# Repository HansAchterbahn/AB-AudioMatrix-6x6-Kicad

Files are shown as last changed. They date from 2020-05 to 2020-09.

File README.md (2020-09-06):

# AB AudioMatrix 6×6

Active audio matrix (6×6), that can map 6 input channels (1-6) to 6 output channels (A-F). Connection via 3.5 jack cable. Compatible with line signals, aux, headphones and active speakers. Each output channel can map one input channel at a time.

*Fork me and have fun!*

## 1 Content and Structure

| File / Folder | Abbreviation | Description |
| --- | --- | --- |
| /3d/ | 3D models | Files to work with in a 3D CAD program |
| /bom/ | Bill of Material | Files with needed components and corresponding order number from different distributors |
| /case/ | Case for PCB | Files with an example case for the PCBs |
| /doc/ | Documentation | Files needed in README.md to document the repository |
| /gerber/ | Gerber files | Files exported from Board Layout to order the PCBs from a manufacturer |
| /sch/ | Schematic | Additional schematic files |
| /AB-AudioMatrix-6x6.pro | — | Kicad Project File |
| /AB-AudioMatrix-6x6.sch | — | Root schematic files |
| /AB-AudioMatrix-6x6.kicad_pcb | — | PCB / Board Layout File |
| /LICENSE.md | — | File contains project license |
| /README.md | — | Markdown file with the documentation you are reading now |

## 2 Power Supply Modes

| Mode | + | — | ⊥ | Jumper JP1 | U7, R25, R26  | Info |
| --- | --- | --- | --- | --- | --- | --- |
| Symmetric  | +2.5 to +15 V | -2.5 to -15 V | 0V  | Open | not necessary | Highly recommended for good Sound and clearly separated channels  |
| Asymmetric | +5 to +30 V | 0 V | --- | Closed | necessary | Possible, but not recommended; Channels are not clearly separated |

## 3 Pictures

### 3.1 Mounted device

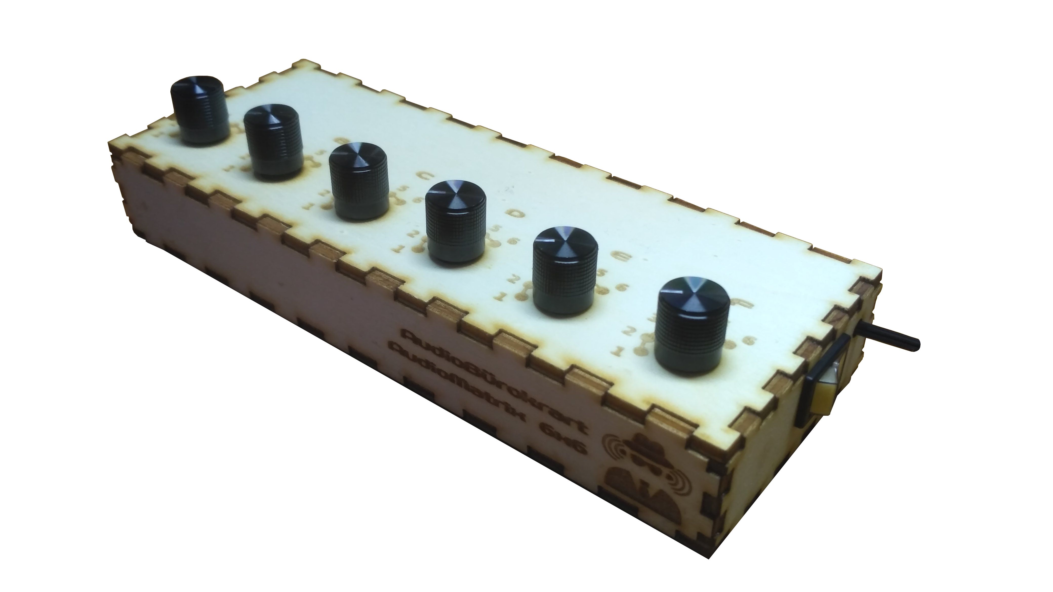
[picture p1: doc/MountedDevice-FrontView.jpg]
Front view

Front view

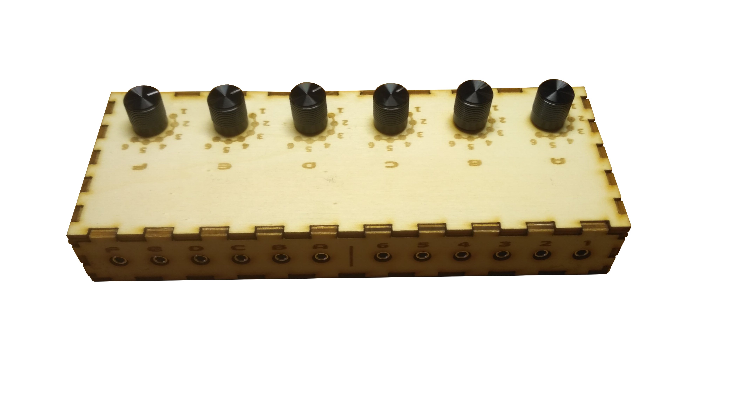
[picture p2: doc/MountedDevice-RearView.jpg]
Rear view

Rear view

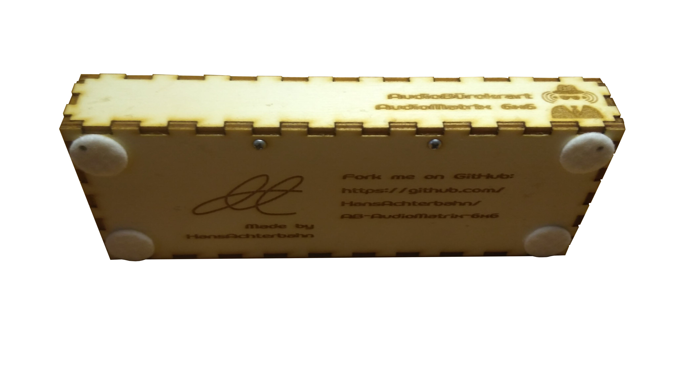
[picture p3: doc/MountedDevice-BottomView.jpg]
Bottom view

Bottom view

### 3.2 Board

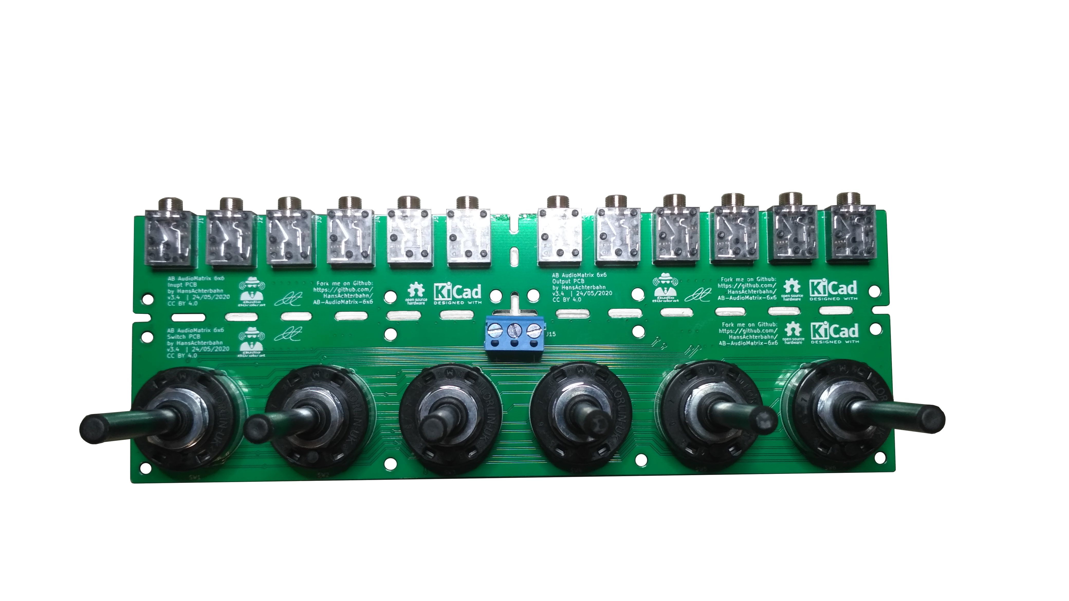
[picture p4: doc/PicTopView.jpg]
Top view

Top view

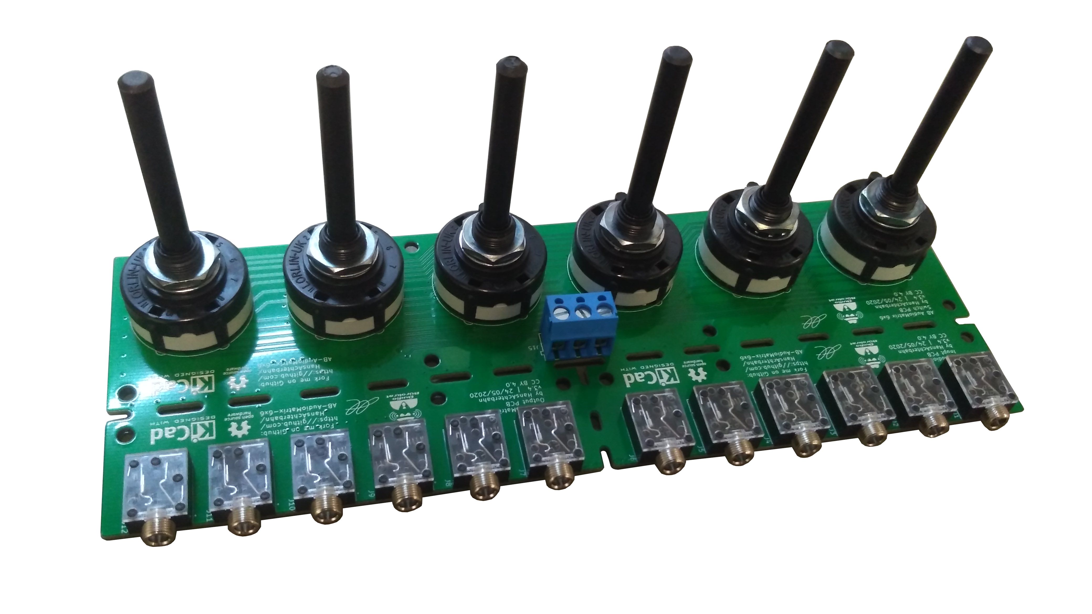
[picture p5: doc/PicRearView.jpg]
Rear view

Rear view

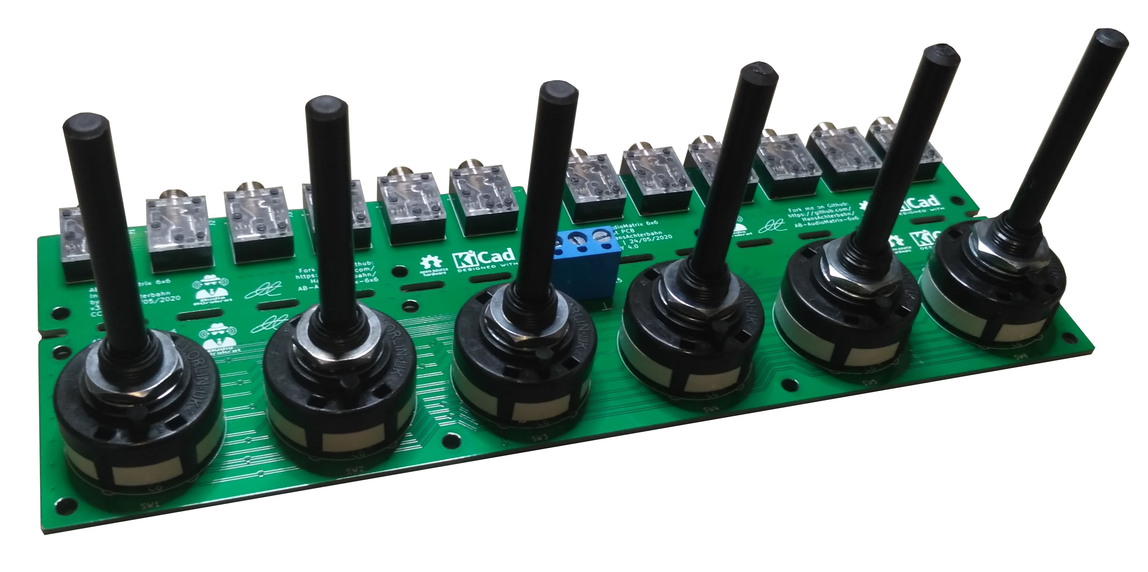
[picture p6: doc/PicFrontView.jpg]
Front view


<!--
## 4 CAD Data

![Top view](doc/3d-TopView.png)
Top view

![Front view ](doc/3d-FrontView.png)
Front view

![Rear view](doc/3d-RearView.png)
Rear view

![Bottom view](doc/3d-BottomView.png)
Bottom view
-->

## 4 Schematic

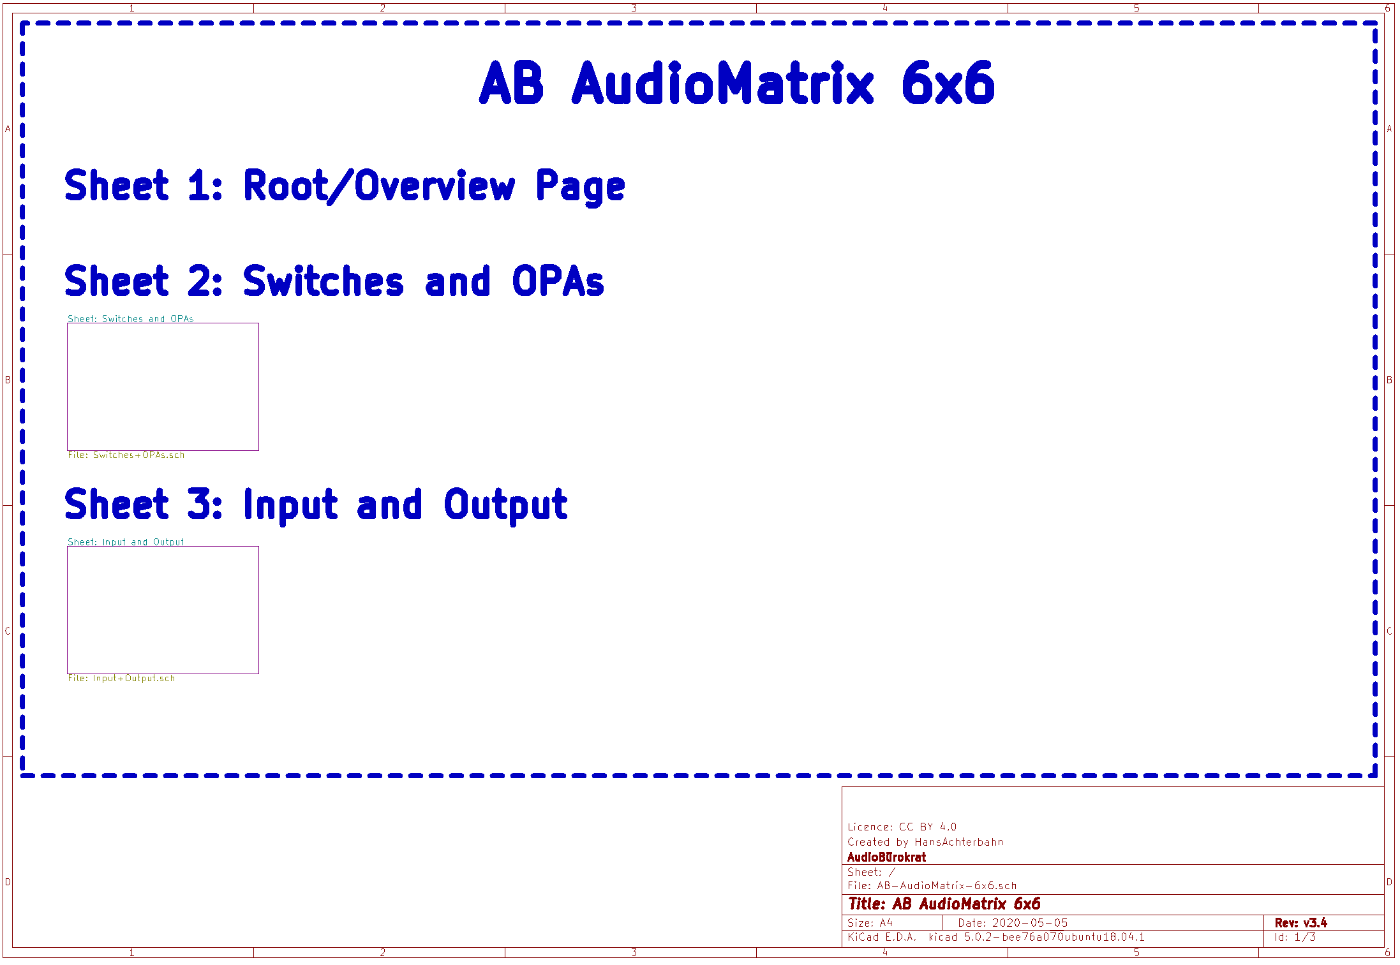
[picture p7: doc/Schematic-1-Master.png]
Sheet 1: Root / Overview Page

Sheet 1: Root / Overview Page

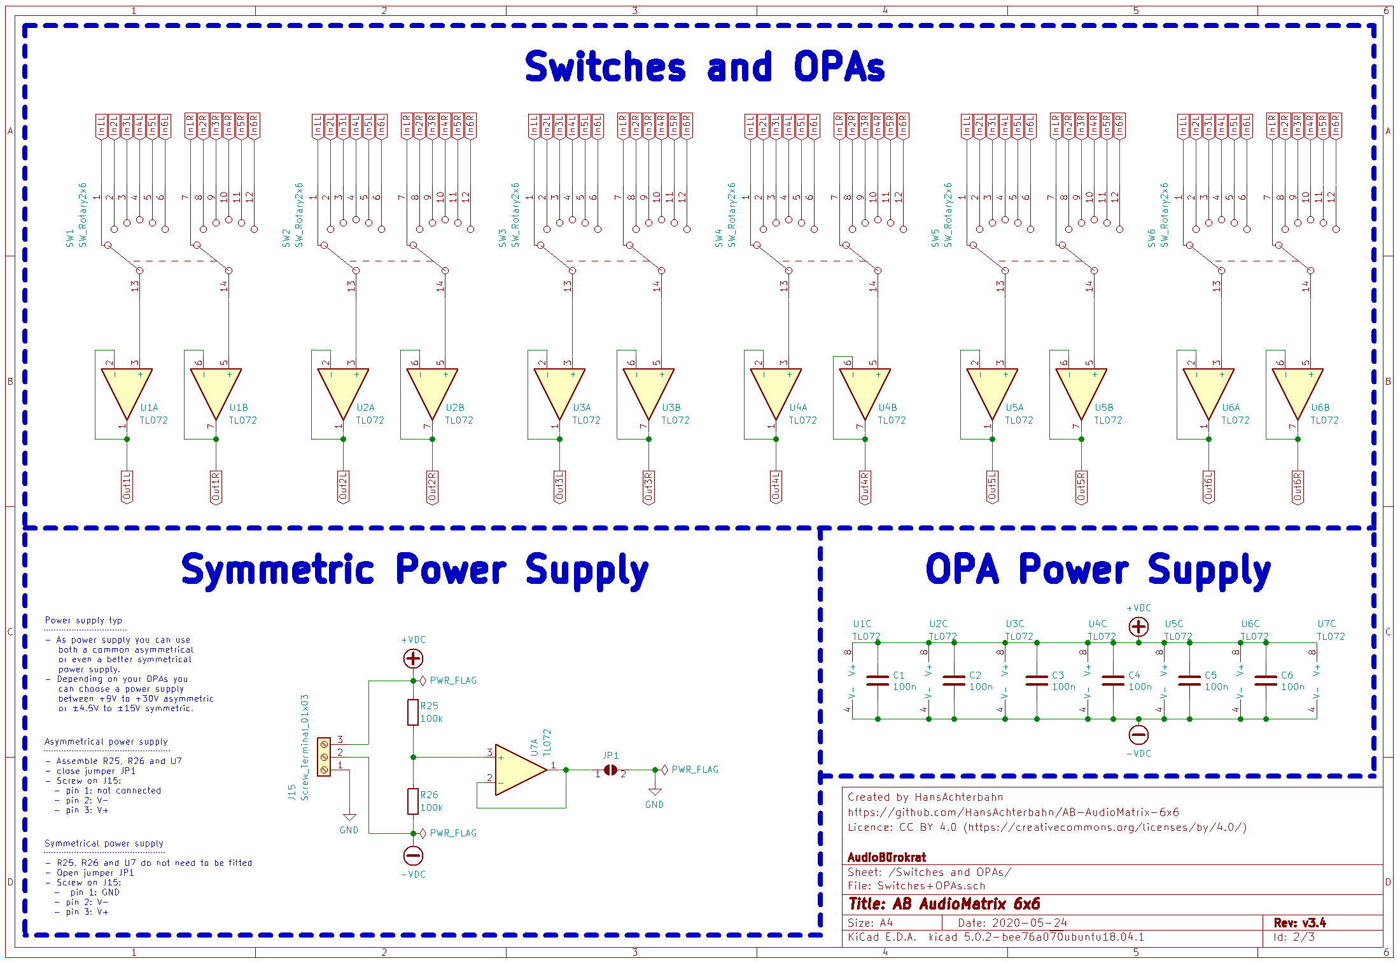
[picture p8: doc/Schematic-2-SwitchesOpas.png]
Sheet 2: Switches and OPAs

Sheet 2: Switches and OPAs

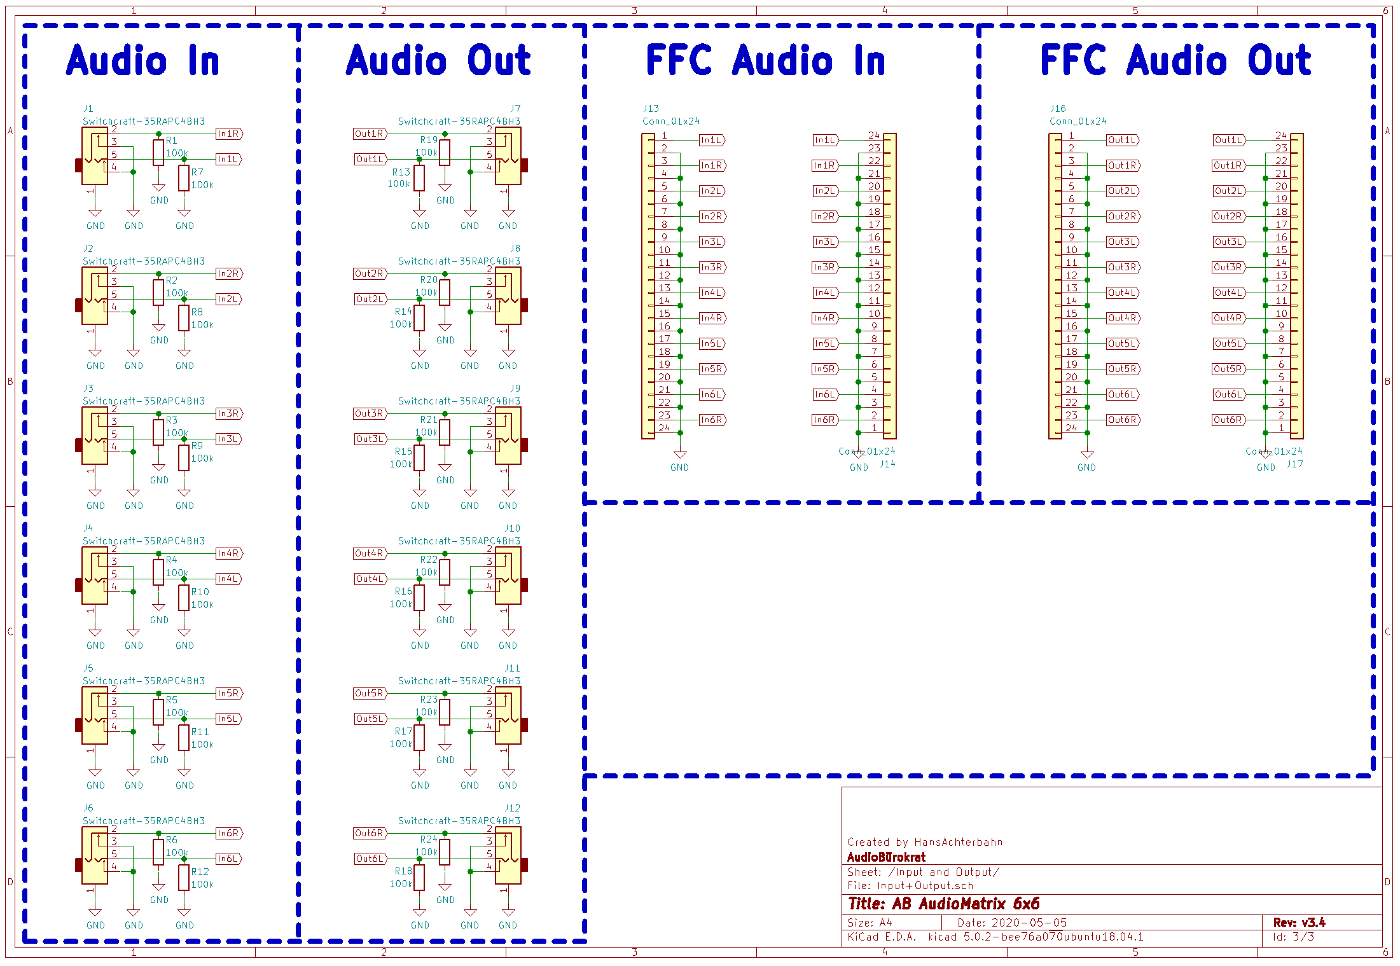
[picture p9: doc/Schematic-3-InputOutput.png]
Sheet 3: Audio Input and Output

Sheet 3: Audio Input and Output

## 5 Board Layout

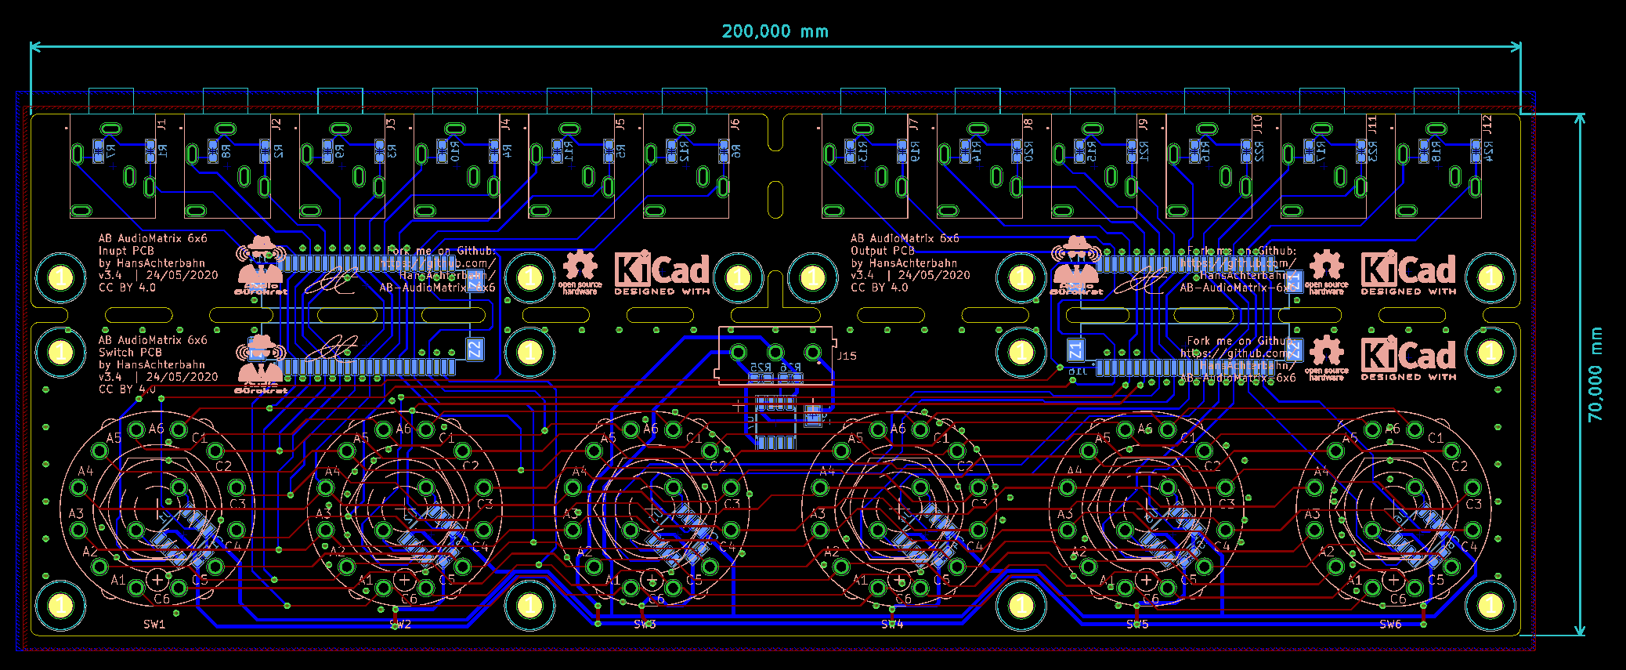
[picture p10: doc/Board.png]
PCB / Board layout

PCB / Board layout

## 6 License

<p xmlns:dct="http://purl.org/dc/terms/" xmlns:cc="http://creativecommons.org/ns#" class="license-text"><a rel="cc:attributionURL" href="https://github.com/HansAchterbahn/AB-AudioMatrix-6x6"><span rel="dct:title">AB AudioMatrix 6×6</span></a> by <a rel="cc:attributionURL" href="https://github.com/HansAchterbahn/"><span rel="cc:attributionName">Hans Achterbahn </span></a>CC BY 4.0 </p>

AudioBürokrat Logo

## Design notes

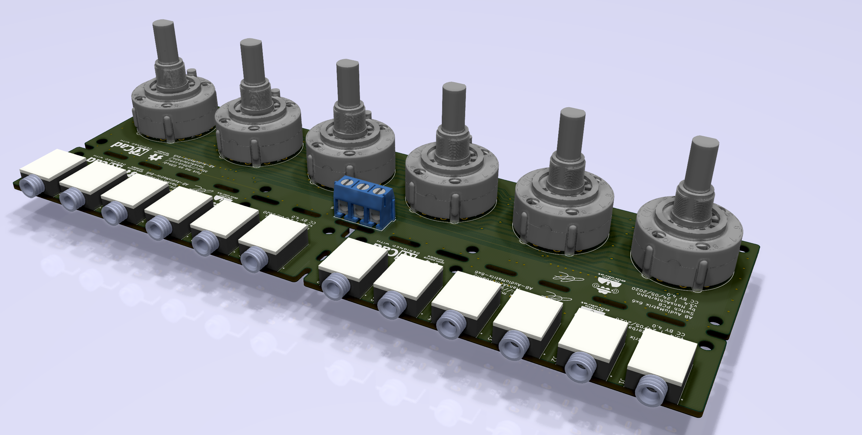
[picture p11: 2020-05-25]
doc/3d-RearView.png

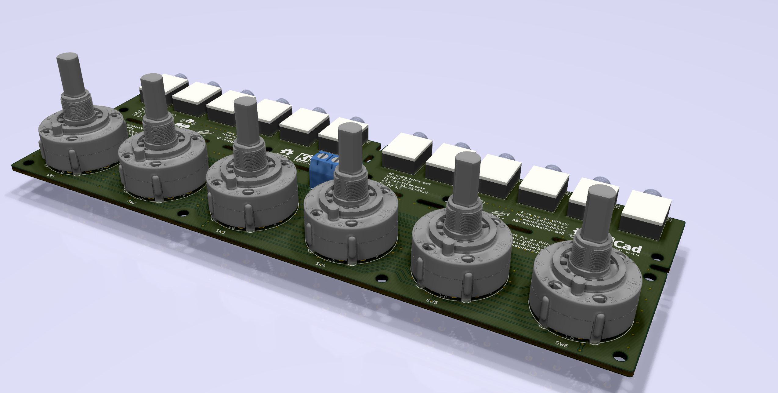
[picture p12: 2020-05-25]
doc/3d-FrontView.png

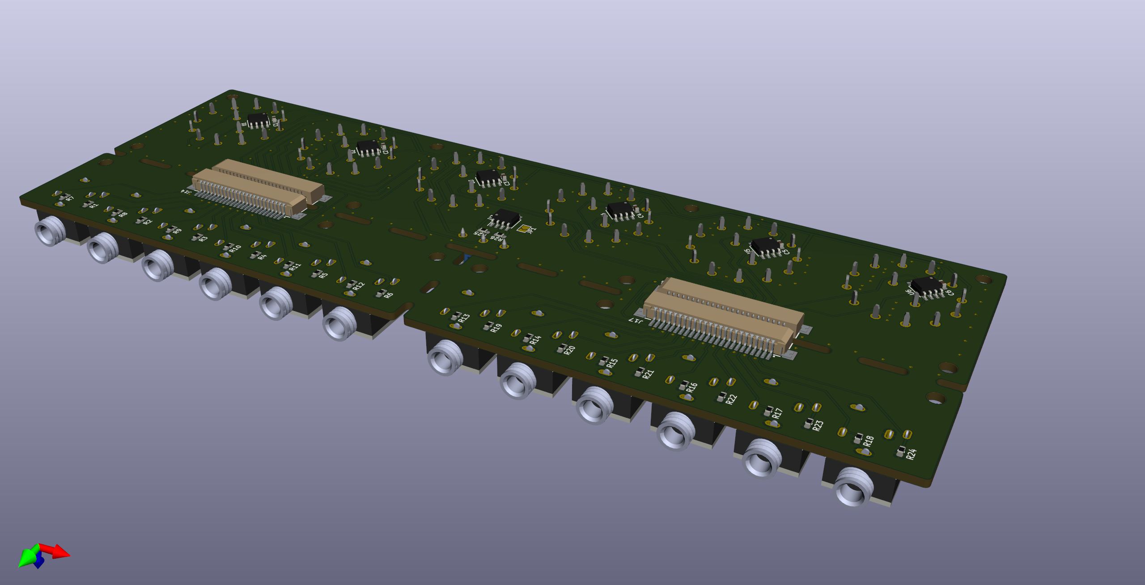
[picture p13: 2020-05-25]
doc/3d-BottomView.png

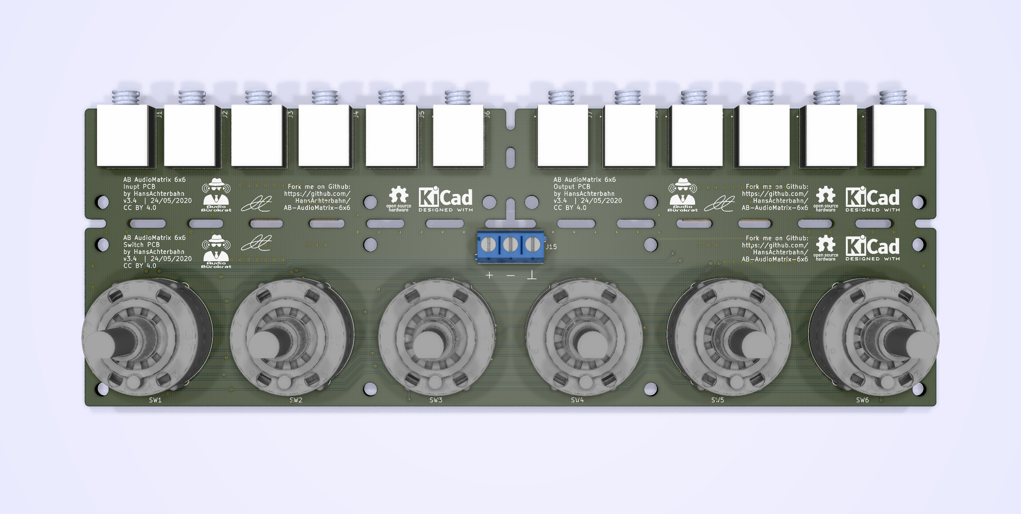
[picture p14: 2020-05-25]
doc/3d-TopView.png

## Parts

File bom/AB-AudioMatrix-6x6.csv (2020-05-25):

Reference | Quantity | Value | Footprint | Datasheet | Digi-Key | Infopage | MF | MFN | Mouser | RS-Online
C1 C2 C3 C4 C5 C6 | 6 | 100n | Capacitor_SMD:C_0603_1608Metric_Pad1.05x0.95mm_HandSolder | https://www.mouser.de/datasheet/2/447/UPY-GPHC_X7R_6.3V-to-50V_18-1154002.pdf | 311-1779-1-ND | — | Yageo | CC0603JRX7R9BB104 | 603-CC603JRX7R9BB104 | 200-6519
J1 J10 J11 J12 J2 J3 J4 J5 J6 J7 J8 J9 | 12 | Switchcraft-35RAPC4BH3 | h8-Connectors:Switchcraft-35RAPC4BH3 | http://www.switchcraft.com/Drawings/35rapc__h3_cd.pdf | SC1464-ND | http://www.switchcraft.com/ProductSummary.aspx?Parent=425 | Switchcraft | 35RAPC4BH3 | 502-35RAPC4BH3 | 35RAPC4BH3
J13 J14 J16 J17 | 4 | Conn_01x24 | h8-Connectors:Wuerth-686124188622 | https://www.we-online.com/catalog/datasheet/686124188622.pdf | 732-686124188622CT-ND | https://www.we-online.com/catalog/en/FPC_1_00_SMT_LIF_HORIZONTAL_TOP_CONTACT_6861xx188622 | Wuerth | 686124188622 | 710-686124188622 | —
J15 | 1 | Screw_Terminal_01x03 | h8-Connectors:Wuerth-691102710003 | https://www.we-online.de/katalog/datasheet/691102710003.pdf | 732-2029-ND | https://www.we-online.de/katalog/de/TBL_5_00_102_6911027100XX/ | Wuerth | 691102710003 | 710-691102710003 | 691102710003
JP1 | 1 | SolderJumper_2_Open | Jumper:SolderJumper-2_P1.3mm_Open_TrianglePad1.0x1.5mm | — | — | — | — | — | — | —
R1 R10 R11 R12 R13 R14 R15 R16 R17 R18 R19 R2 R20 R21 R22 R23 R24 R25 R26 R3 R4 R5 R6 R7 R8 R9 | 26 | 100k | Resistor_SMD:R_0603_1608Metric_Pad1.05x0.95mm_HandSolder | https://www.mouser.de/datasheet/2/427/crcwce3-1762584.pdf | 541-3950-1-ND | — | Vishay | CRCW0603100KFKEAC | 71-CRCW0603100KFKEAC | 820-6745
SW1 SW2 SW3 SW4 SW5 SW6 | 6 | SW_Rotary2x6 | h8-Switches:CK102X06 | https://lorlinelectronics.co.uk/wp-content/uploads/2020/03/CK_Datasheet_Mar_2020.pdf | — | https://lorlinelectronics.co.uk/product/ck | Lorlin | CK1050 | — | 665-196
U1 U2 U3 U4 U5 U6 U7 | 7 | TL072 | Package_SO:SOIC-8_3.9x4.9mm_P1.27mm | https://www.ti.com/lit/ds/symlink/tl072.pdf?ts=1590259660482 | 296-1282-2-ND | https://www.ti.com/store/ti/en/p/product/?p=TL072CDR | TI | TL072CDR | 595-TL072CDR | 197-7552

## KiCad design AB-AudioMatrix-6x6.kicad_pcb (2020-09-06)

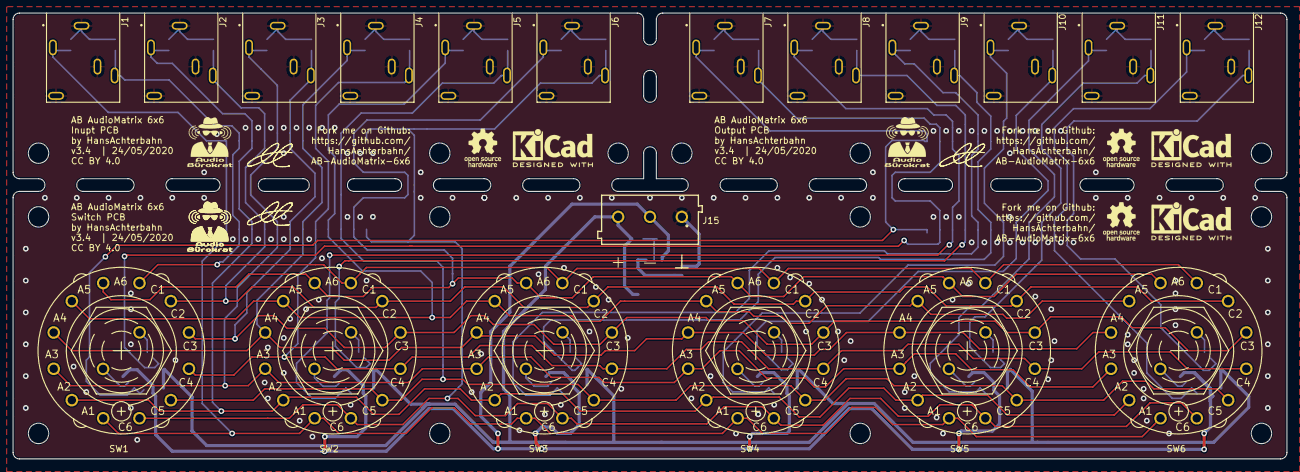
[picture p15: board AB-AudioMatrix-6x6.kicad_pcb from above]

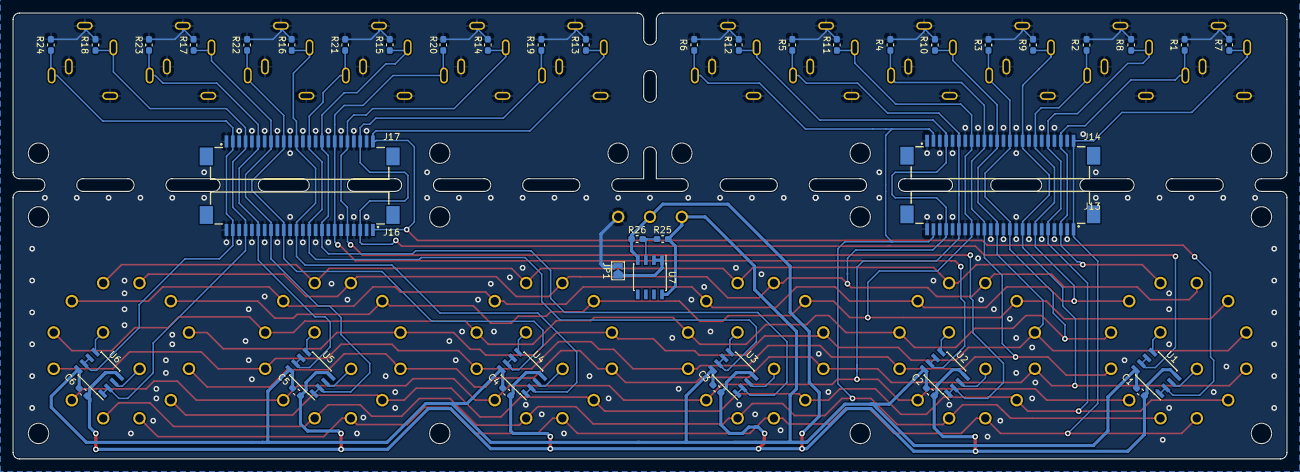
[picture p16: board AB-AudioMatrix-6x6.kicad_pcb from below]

Board: 4 copper layers, 200.0 x 70.0 mm, 63 parts (44 on the bottom side), 41 nets.

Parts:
C1, C2, C3, C4, C5, C6: 100n; C_0603_1608Metric_Pad1.05x0.95mm_HandSolder
J1, J2, J3, J4, J5, J6, J7, J8, J9, J10, J11, J12: Switchcraft-35RAPC4BH3
J13, J14, J16, J17: Conn_01x24; Wuerth-686124188622
J15: Screw_Terminal_01x03; Wuerth-691102710003
JP1: SolderJumper_2_Open; SolderJumper-2_P1.3mm_Open_TrianglePad1.0x1.5mm
R1, R2, R3, R4, R5, R6, R7, R8, R9, R10, R11, R12, R13, R14, R15, R16, R17, R18, R19, R20, R21, R22, R23, R24, R25, R26: 100k; R_0603_1608Metric_Pad1.05x0.95mm_HandSolder
SW1, SW2, SW3, SW4, SW5, SW6: SW_Rotary2x6; CK102X06
U1, U2, U3, U4, U5, U6, U7: TL072; SOIC-8_3.9x4.9mm_P1.27mm

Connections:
+VDC: C1.1, C2.1, C3.1, C4.1, C5.1, C6.1, J15.3, R25.2, U1.8, U2.8, U3.8, U4.8, U5.8, U6.8, U7.8
-VDC: C1.2, C2.2, C3.2, C4.2, C5.2, C6.2, J15.2, R26.1, U1.4, U2.4, U3.4, U4.4, U5.4, U6.4, U7.4
GND: J1.1, J1.3, J1.4, J2.1, J2.3, J2.4, J3.1, J3.3, J3.4, J4.1, J4.3, J4.4, J5.1, J5.3, J5.4, J6.1, J6.3, J6.4, J7.1, J7.3, J7.4, J8.1, J8.3, J8.4, J9.1, J9.3, J9.4, J10.1, J10.3, J10.4, J11.1, J11.3, J11.4, J12.1, J12.3, J12.4, J13.2, J13.4, J13.6, J13.8, J13.10, J13.12, J13.14, J13.16, J13.18, J13.20, J13.22, J13.24, J14.1, J14.3, J14.5, J14.7, J14.9, J14.11, J14.13, J14.15, J14.17, J14.19, J14.21, J14.23, J15.1, J16.2, J16.4, J16.6, J16.8, J16.10, J16.12, J16.14, J16.16, J16.18, J16.20, J16.22, J16.24, J17.1, J17.3, J17.5, J17.7, J17.9, J17.11, J17.13, J17.15, J17.17, J17.19, J17.21, J17.23, JP1.2, R1.2, R2.2, R3.2, R4.2, R5.2, R6.2, R7.2, R8.2, R9.2, R10.2, R11.2, R12.2, R13.1, R14.1, R15.1, R16.1, R17.1, R18.1, R19.1, R20.1, R21.1, R22.1, R23.1, R24.1
In1L: J1.5, J13.1, J14.24, R7.1, SW1.1, SW2.1, SW3.1, SW4.1, SW5.1, SW6.1
In1R: J1.2, J13.3, J14.22, R1.1, SW1.7, SW2.7, SW3.7, SW4.7, SW5.7, SW6.7
In2L: J2.5, J13.5, J14.20, R8.1, SW1.2, SW2.2, SW3.2, SW4.2, SW5.2, SW6.2
In2R: J2.2, J13.7, J14.18, R2.1, SW1.8, SW2.8, SW3.8, SW4.8, SW5.8, SW6.8
In3L: J3.5, J13.9, J14.16, R9.1, SW1.3, SW2.3, SW3.3, SW4.3, SW5.3, SW6.3
In3R: J3.2, J13.11, J14.14, R3.1, SW1.9, SW2.9, SW3.9, SW4.9, SW5.9, SW6.9
In4L: J4.5, J13.13, J14.12, R10.1, SW1.4, SW2.4, SW3.4, SW4.4, SW5.4, SW6.4
In4R: J4.2, J13.15, J14.10, R4.1, SW1.10, SW2.10, SW3.10, SW4.10, SW5.10, SW6.10
In5L: J5.5, J13.17, J14.8, R11.1, SW1.5, SW2.5, SW3.5, SW4.5, SW5.5, SW6.5
In5R: J5.2, J13.19, J14.6, R5.1, SW1.11, SW2.11, SW3.11, SW4.11, SW5.11, SW6.11
In6L: J6.5, J13.21, J14.4, R12.1, SW1.6, SW2.6, SW3.6, SW4.6, SW5.6, SW6.6
In6R: J6.2, J13.23, J14.2, R6.1, SW1.12, SW2.12, SW3.12, SW4.12, SW5.12, SW6.12
unnamed: JP1.1, U7.1, U7.2
unnamed: R25.1, R26.2, U7.3
unnamed: SW1.13, U1.3
unnamed: SW1.14, U1.5
unnamed: SW2.13, U2.3
unnamed: SW2.14, U2.5
unnamed: SW3.13, U3.3
unnamed: SW3.14, U3.5
unnamed: SW4.13, U4.3
unnamed: SW4.14, U4.5
unnamed: SW5.13, U5.3
unnamed: SW5.14, U5.5
unnamed: SW6.13, U6.3
unnamed: SW6.14, U6.5
Out1L: J7.5, J16.1, J17.24, R13.2, U1.1, U1.2
Out1R: J7.2, J16.3, J17.22, R19.2, U1.6, U1.7
Out2L: J8.5, J16.5, J17.20, R14.2, U2.1, U2.2
Out2R: J8.2, J16.7, J17.18, R20.2, U2.6, U2.7
Out3L: J9.5, J16.9, J17.16, R15.2, U3.1, U3.2
Out3R: J9.2, J16.11, J17.14, R21.2, U3.6, U3.7
Out4L: J10.5, J16.13, J17.12, R16.2, U4.1, U4.2
Out4R: J10.2, J16.15, J17.10, R22.2, U4.6, U4.7
Out5L: J11.5, J16.17, J17.8, R17.2, U5.1, U5.2
Out5R: J11.2, J16.19, J17.6, R23.2, U5.6, U5.7
Out6L: J12.5, J16.21, J17.4, R18.2, U6.1, U6.2
Out6R: J12.2, J16.23, J17.2, R24.2, U6.6, U6.7

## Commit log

2020-05-12 Complete schematic | started PCB
    [AB-AudioMatrix-6x6.kicad_pcb, AB-AudioMatrix-6x6.sch, Input+Output.sch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]
2020-05-13 added Edge.Cuts | devices arranged on PCB | added GND planes
    [AB-AudioMatrix-6x6.kicad_pcb, Input+Output.sch]
2020-05-14 added converter for asymmetric power supply | Routing In & Out PCB finished | Routing Switch PCB started
    [AB-AudioMatrix-6x6.kicad_pcb, AB-AudioMatrix-6x6.sch, Input+Output.sch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]
2020-05-16 Routing switches complete
    [AB-AudioMatrix-6x6.kicad_pcb]
2020-05-16 Routing Input FFC connector to switches
    [AB-AudioMatrix-6x6.kicad_pcb]
2020-05-17 swaped supply pins | routing complete → routing revision and optimization necessary
    [AB-AudioMatrix-6x6.kicad_pcb, Switches+OPAs.sch]
2020-05-18 finished routing | added GND polygon | added description in surface plot | added pictures to README.md documentation | changed LICENCE.md to CC BY 4.0
    [AB-AudioMatrix-6x6.kicad_pcb, Input+Output.sch, Switches+OPAs.sch]
2020-05-18 Date updated and Github link added to schematic and board
    [AB-AudioMatrix-6x6.kicad_pcb, AB-AudioMatrix-6x6.sch]
2020-05-24 added new attributes MF, MFN, Mouser, Digi-Key, RS-Online, Infopage, datasheet | bill of material (BOM) created | infobox updated | added AudioBürokrat logo on silkscreen
    [AB-AudioMatrix-6x6.kicad_pcb, AB-AudioMatrix-6x6.sch, Input+Output.sch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]
2020-05-24 Added BOM files in .gitignore
    [AB-AudioMatrix-6x6.csv]
2020-05-25 changed AudioBürokrat logo
    [AB-AudioMatrix-6x6.kicad_pcb]
2020-05-25 added folder for BOM
    [AB-AudioMatrix-6x6.csv]
2020-05-25 changed AudioBürokrat logo (Bitmap import)
    [AB-AudioMatrix-6x6.kicad_pcb]
2020-05-25 moved additional schematic sheets to folder sch | updated README.md
    [S-Input+Output.sch, S-Switches+OPAs.sch, _saved_AB-AudioMatrix-6x6.sch]
2020-05-25 updated schematic
    [AB-AudioMatrix-6x6.sch, _saved_AB-AudioMatrix-6x6.sch]
2020-05-25 Gerber files generated
    [AB-AudioMatrix-6x6-B.Cu.gbr, AB-AudioMatrix-6x6-B.Mask.gbr, AB-AudioMatrix-6x6-B.Paste.gbr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]
2020-05-25 changed 3D path for some footprints on PCB | started 3D Model in FreeCAD
    [AB-AudioMatrix-6x6.kicad_pcb]
2020-06-22 Update README.md → added PCB pictures | added chapter _Power Supply_
2020-06-22 Update README.md → changed parts in _Power Supply_ | croped first picture
2020-07-24 Changed 3d Model | added 3D STL Format | added Lasercutter Case
2020-07-28 optimized lasercutter case
2020-09-04 laser cutter case: added cuts for switch and power cable
2020-09-05 laser cutter case: cut tested + tiny optimization + deleted unused parts
2020-09-06 README.md: Added pics of mounted device | pics exposed from surroundings | small optimizations

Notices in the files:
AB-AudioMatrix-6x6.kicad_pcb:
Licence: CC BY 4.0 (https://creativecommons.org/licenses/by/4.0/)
